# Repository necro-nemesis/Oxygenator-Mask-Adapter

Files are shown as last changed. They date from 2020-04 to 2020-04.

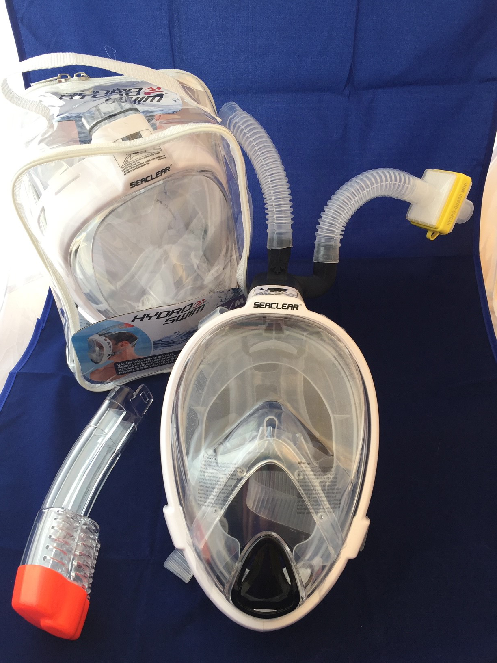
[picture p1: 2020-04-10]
Hydro Swim adapter.jpg

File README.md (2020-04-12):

# Oxygenator-Mask-Adapter
Open source design to convet a Hydro-Swim diving mask into a full face oxygenator mask.

Shield: [][cc-by-sa]

This work is licensed under a [Creative Commons Attribution-ShareAlike 4.0
International License][cc-by-sa].

[][cc-by-sa]

[cc-by-sa]: http://creativecommons.org/licenses/by-sa/4.0/
[cc-by-sa-image]: https://licensebuttons.net/l/by-sa/4.0/88x31.png
[cc-by-sa-shield]: https://img.shields.io/badge/License-CC%20BY--SA%204.0-lightgrey.svg

## Assembly (Snap on inlet/outlet fitting and blow out valve snap in plug)




The oxygenator-mask-adapter has been deigned to be fitted to the Hydro-Swim Seaclear Vista Snorkeling Mask manufactured by Bestway www.bestwaycorp.com/support.

I have provided .stl files for quick access to 3d printing. The slicer you use should only require minimal support material immediately under the two round hose connections. Also ensure that it is selected to add support only to areas in contact with the build plate. No internal support is required. Additionally I have provided STEP and SAT files for the ability to work on other adaptations. I have printed the files at various layer heights and have had a working part at .3mm layer height with a .4mm nozzel if time is critical although fitment is better at higher resolutions if you have the luxury of time to print them. .2mm layer height is a good compromise. It is recommended to use PLA due to it's inert nature.

The blow out valve plug must be utilized to block the front blowout port. It is a snap in design.

The project commenced in response to identifiable shortages in ventilators and related equipment during the outbreak of COVID 19d. 

This valve design has been adapted from Issinova's design to use the Bestway mask. If you have access to Ocean Reef or Mares masks the files to produce a valve can be obtained here. https://www.isinnova.it/easy-covid19-eng/.

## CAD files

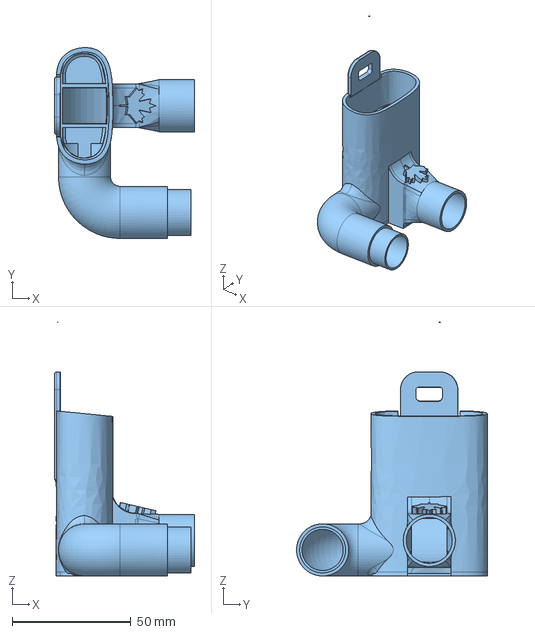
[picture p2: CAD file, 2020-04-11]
Canadian_glen_valve.stp
59.3 x 80.5 x 107.2 mm

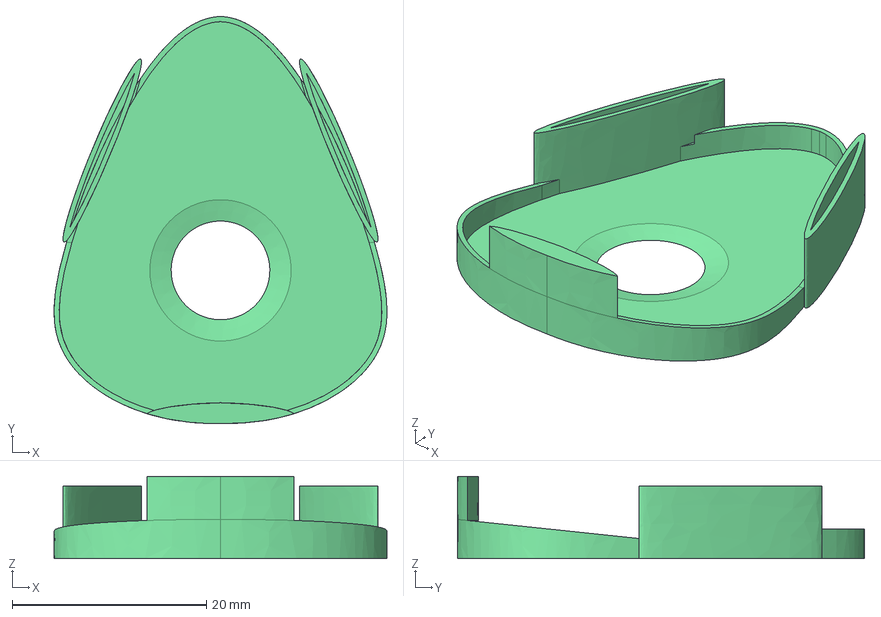
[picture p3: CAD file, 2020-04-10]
plug.stp
34.3 x 41.9 x 8.48 mm

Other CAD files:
plug.stl

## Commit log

2020-04-11 Added protective mask adapter / revised connection
    Provided a fitting to install an Intersurgical 1745000 filter into the port to convert the mask into a protective mask. Additionally tightened tolerance to the O ring for a tighter seal.
    [Canadian_glen_protective.stl, Canadian_glen_protective.stp, Canadian_glen_valve.stp]
2020-04-11 Posted to separate repo.
    [Canadian_glen_protective.stl]

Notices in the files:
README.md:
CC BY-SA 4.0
